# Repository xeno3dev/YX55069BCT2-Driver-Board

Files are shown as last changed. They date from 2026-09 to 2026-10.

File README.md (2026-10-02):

PCB Render



# LumaDD

## Overview

LumaDD is a Custom Display Driver Board designed around a display I got off [Alibaba](https://www.alibaba.com/product-detail/5-5-Vertical-Smart-Home-lcd_1601790231031.html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), with Touch Support. It features HDMI -> MIPI DSI video signal conversion, USB-C for Touch Signals + Power, as well as an onboard ESP32-S3 for display control + touch processing (via USB HID)

## Repo Directory

Folder | Contents
|---|---|
Component Libs | All 3D Models. Footprints, and Symbols used on the PCB
Kicad Project | Schematic + PCB Files
Production Files | BOM + CPL + Netlist + Designator + Gerber Files

## Rough BOM
| Part / Group | What’s included | Qty | Cost (USD) |
| --- | --- | ---: | ---: |
| Converter BGA | [TC358870XBG](https://www.lcsc.com/product-detail/C3008712.html), U1 | 1 | $8.86 |
| ESP32 by itself | [ESP32-S3R8](https://www.lcsc.com/product-detail/C2913194.html), U10 | 1 | $3.02 |
| Flash memory | [GD25Q128EWIGR](https://www.lcsc.com/product-detail/C2982923.html), U11 | 1 | $3.33 |
| HDMI port | [Amphenol 10029449-111RLF](https://www.lcsc.com/product-detail/C427307.html) | 1 | $0.62 |
| USB-C port | [TYPE-C16PIN](https://www.lcsc.com/product-detail/C393939.html) | 1 | $0.06 |
| Display connector | [24-pin FPC](https://www.lcsc.com/product-detail/C132514.html) | 1 | $0.25 |
| Touch connector | [6-pin FPC](https://www.lcsc.com/product-detail/C5343255.html) | 1 | $0.15 |
| Power regulation and input control | Five TLV767 regulators, CH224K, TPS259474 eFuse | 7 | $3.64 |
| Backlight power stage | TPS61165, inductor, diode | 3 | $1.09 |
| Logic level shifters | Two PCA9306, TXS0101, SN74AXC1T45 | 4 | $2.39 |
| ESD / surge protection | D3–D5, U8, U12, U16 | 6 | $1.46 |
| Clock components | 40 MHz crystal and 48 MHz oscillator | 2 | $1.50 |
| Boot / reset buttons | SW3 and SW4 | 2 | $2.29 |
| Capacitors | All BOM capacitors | 72 | $1.97 |
| Resistors | All BOM resistors | 40 | $0.36 |
| MOSFETs | Three BSS138 | 3 | $0.06 |
| Ferrite beads | FB1 and FB2 | 2 | $0.03 |
| **Total parts used** | **148 components** | **148** | **$31.07** |

### Full BOM Located [Here](./Production%20Files/bom.csv)

## License

[Attribution-NonCommercial-ShareAlike 4.0 International](./LICENSE)

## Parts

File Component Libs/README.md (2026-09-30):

# YX55069BCT2 portable KiCad library

`YX55069BCT2.kicad_sym` and `YX55069BCT2.pretty` are self-contained
project libraries. The project tables in `../Kicad Project/` address them by a
project-relative path, so a clone needs neither the Slate113 checkout nor global
KiCad libraries.

The exact requested parts carry their MPN, manufacturer, LCSC part number,
datasheet, and local footprint as symbol properties. `manifest.json` records
the source library and source hash. `tools/build_library.py` reproduces the
library from those sources; normal project use does not run it.

Matching STEP models are stored in `YX55069BCT2.3dshapes` with project-relative
paths. After regenerating the footprint library, run `tools/assign_3d_models.py`
to restore the 3D links in both the library and PCB. The TC358870 BGA STEP came
from EasyEDA/LCSC C3008712, the USB-C STEP from Slate113, and the remaining
models from recorded vendor imports or matching KiCad standard packages.

- `ESP32-S3-WROOM-1-N16R8` uses the PCB-antenna WROOM-1 land pattern. GPIO35,
  GPIO36, and GPIO37 are marked `RESERVED_PSRAM` because N16R8 uses octal
  PSRAM.
- `TC358870XBG(NOK)` is C3008712. Its 1.1 V core/HDMI rails, 1.2 V MIPI D-PHY
  rails, 1.8 V I/O, and 3.3 V I/O/HDMI rails must remain separate.
- `AP2112K-1.2TRG1` was added for the TC358870 1.2 V rail. The requested
  1.8 V and 3.3 V AP2112s and 2.8 V AP2120 remain available.
- The bridge needs an I2C host to set its registers, EDID SRAM and panel
  parameters; it is not a generic plug-and-play MIPI-panel adapter.

See [SOURCING_AND_ARCHITECTURE.md](SOURCING_AND_ARCHITECTURE.md) for sourcing
status and the schematic integration constraints.

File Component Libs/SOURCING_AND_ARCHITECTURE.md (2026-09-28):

# Display bridge sourcing and board architecture

Stock was checked on global LCSC product/catalog pages and DigiKey on
2026-09-24. Search-card availability was not used as evidence.

## Exact board components

This board is HDMI input -> TC358870 -> MIPI DSI panel, with a separate USB-C
USB 2.0 cable for touch. It is not a USB-C DisplayPort Alt Mode display input.
The USB-C connector is therefore only the ESP32 USB device path: D+/D-, ESD,
and two separate 5.1 kohm CC pull-downs. It must not connect to the bridge's
HDMI receiver or DSI output.

| Function | Exact fitted component | LCSC | Documentation |
| --- | --- | --- | --- |
| HDMI input | Amphenol 10029449-001RLF | [C428493](https://www.lcsc.com/product-detail/C428493.html) | [drawing](https://cdn.amphenol-icc.com/media/wysiwyg/files/drawing/10029449.pdf) |
| HDMI to DSI | Toshiba TC358870XBG(NOK) | [C3008712](https://www.lcsc.com/product-detail/C3008712.html) | [datasheet](https://toshiba.semicon-storage.com/info/TC358870XBG_datasheet_en_20171025.pdf?did=28743&prodName=TC358870XBG) |
| Touch HID MCU | ESP32-S3-WROOM-1-N16R8 | [C2913202](https://www.lcsc.com/product-detail/C2913202.html) | [Espressif](https://www.espressif.com/sites/default/files/documentation/esp32-s3-wroom-1_wroom-1u_datasheet_en.pdf) |
| USB-C USB 2.0 | Shou Han TYPE-C16PIN | [C393939](https://www.lcsc.com/product-detail/C393939.html) | — |
| Optional USB-C PD sink | STMicroelectronics STUSB4500QTR | [C2678061](https://www.lcsc.com/product-detail/C2678061.html) | [ST datasheet](https://www.st.com/resource/en/datasheet/stusb4500.pdf) |
| Display FPC | CKMTW F-FPC0M24P-C310 | [C132514](https://www.lcsc.com/product-detail/C132514.html) | — |
| Touch FPC | Xunpu FPC-0.5FX-6PWBH10 | [C5343255](https://www.lcsc.com/product-detail/C5343255.html) | — |
| I2C translation | TI PCA9306DCUR | [C33196](https://www.lcsc.com/product-detail/C33196.html) | [TI](https://www.ti.com/product/PCA9306) |
| USB ESD | ST USBLC6-2SC6 | [C7519](https://www.lcsc.com/product-detail/C7519.html) | [ST](https://www.st.com/resource/en/datasheet/usblc6-2.pdf) |
| 3.3 V LDO | Diodes AP2112K-3.3TRG1 | [C51118](https://www.lcsc.com/product-detail/C51118.html) | [Diodes](https://www.diodes.com/part/view/AP2112) |
| Optional 3.3 V LDO | Seaward Elec SED5120 | [C2838439](https://www.lcsc.com/product-detail/C2838439.html) | [datasheet](https://lcsc.com/datasheet/lcsc_datasheet_2410121612_Seaward-Elec-SED5120_C2838439.pdf) |
| 1.8 V LDO | Diodes AP2112K-1.8TRG1 | [C176944](https://www.lcsc.com/product-detail/C176944.html) | [Diodes](https://www.diodes.com/part/view/AP2112) |
| 2.8 V LDO | Diodes AP2120N-2.8TRG1 | [C6500826](https://www.lcsc.com/product-detail/C6500826.html) | [Diodes](https://www.diodes.com/datasheet/download/AP2120.pdf) |
| 1.2 V LDO | Diodes AP2112K-1.2TRG1 | [C460310](https://www.lcsc.com/product-detail/C460310.html) | [Diodes](https://www.diodes.com/part/view/AP2112) |
| Backlight candidate | TI LP8556SQ-E09/NOPB | [C2679180](https://www.lcsc.com/product-image/C2679180.html) | [TI](https://www.ti.com/lit/ds/symlink/lp8556.pdf) |

The global LCSC product page showed **187** TC358870XBG(NOK) available to ship.
It is HDMI 1.4b RX to MIPI DSI 1.1 TX: 297 MHz HDMI maximum, one four-lane DSI
link at up to 1 Gbit/s/lane, or two four-lane links. The documented single-link
limits are 2558 pixels wide at 24 bpp and 3411 at 16 bpp. It has no scaler or
deinterlacer. With no panel model, resolution, lane count, DCS sequence,
refresh range, backlight string, or FPC pinout, compatibility remains unknown.

TC358870 is **register-configured, not proprietary-firmware booted**. A host
sets its I2C registers, EDID SRAM, and panel control; there is no required
vendor SPI image. Public third-party source exists at
[CNflysky/TC358870](https://github.com/CNflysky/TC358870), but it is not a
manufacturer-supported universal panel binary.

## USB-C DisplayPort Alt Mode -> MIPI DSI

No current global-LCSC or DigiKey part was verified that meets all of: USB-C DP
Alt Mode input, MIPI DSI output, open/publicly sufficient implementation, and
no proprietary vendor firmware.

| Candidate | Direction/capability | Firmware class | Constraint that fails |
| --- | --- | --- | --- |
| LT7911D / C5310990 | Type-C/DP1.2 to MIPI DSI/CSI/LVDS, 1.5 Gbit/s/lane | Factory embedded MCU; confidential documentation | Global LCSC direct route reports part not found. |
| LT7911UXC / C5310989 | Type-C/DP1.4 to MIPI/CSI/LVDS | Factory embedded MCU and SPI-flash firmware | Global LCSC says **Not available now**. |
| Analogix ANX7530/ANX7580 | DP to dual/single MIPI DSI | Public non-proprietary implementation not established | Manufacturer capability exists, but no global LCSC/DigiKey stock was verified. [Analogix](https://www.analogix.com/en/mipi/converters/bridges) |
| TC358870XBG | **HDMI** to DSI | Register-configured | In stock, but wrong input direction for this search. |

Any discrete DP-to-DSI implementation still needs Type-C CC/PD policy,
orientation/lane mapping and normally a high-speed mux. Four DP lanes consume
the SuperSpeed pairs; USB 3.x coexistence means two-lane DP and less bandwidth.
This board needs none of that because its video and touch cables are separate.

## USB-C DP Alt Mode -> HDMI versus MCDP5200B0T

`MCDP5200B0T` was live at DigiKey with **445 pieces**: MPN `MCDP5200B0T`,
orderable as `2763-MCDP5200B0TCT-ND` cut tape,
`2763-MCDP5200B0TTR-ND` reel, or `2763-MCDP5200B0TDKR-ND` Digi-Reel.
[DigiKey listing](https://www.digikey.com/en/products/detail/kinetic-technologies/MCDP5200B0T/13557894).
It has DP1.4a Alt Mode, HDMI 2.0b, HBR3, up to 4K60 RGB/YCC444 or 4K120 YCC420,
and USB3.1 demux. It fails the request because secure boot authenticates a
signed application image from external 16-Mbit SPI flash:
[datasheet brief](https://mm.digikey.com/Volume0/opasdata/d220001/medias/docus/6727/MCDP5200B0T%20Datasheet.pdf).

No currently in-stock functional alternative without proprietary vendor
firmware was verified.

| Candidate | What it replaces | Firmware class | Constraint that fails |
| --- | --- | --- | --- |
| Parade PS176 / C209703 | DP/DP Alt Mode to HDMI 2.0, 4K60 | Factory internal SPI ROM/microcode | Global LCSC says **Not available now**; no open firmware. [Parade](https://www.paradetech.com/products/ps176/) |
| Lontium LT8711GX / C5310994 | Type-C/DP1.4a to HDMI2.1 with CC/PD | Embedded MCU and SPI flash for firmware/HDCP keys | Global LCSC says **Not available now** and the firmware is closed. [LCSC](https://www.lcsc.com/product-detail/C5310994.html) |
| Kinetic STDP2690ADT | Native DP to DP++/HDMI-class output | Internal ROM plus optional external custom flash | DigiKey reports **0 stock** and discontinued. It is HDMI 1.2a/DP++ class and lacks MCDP5200's integrated Type-C/USB3.1 demux. [DigiKey](https://www.digikey.com/en/products/detail/kinetic-technologies/STDP2690ADT/15976326) |

## Schematic integration checklist

- Use controlled-impedance, length-matched HDMI TMDS and MIPI DSI pairs. Route
  DDC, HPD and CEC exactly per the bridge reference material.
- TC358870 needs 1.1 V core/HDMI rails, separate 1.2 V MIPI rails, 1.8 V I/O,
  3.3 V HDMI/I/O rails, local decoupling, 2 kohm REXT, 40-50 MHz 1.8 V REFCLK,
  RESETN, I2C, and accessible test/programming pads.
- SED5120 is an optional nominal 3.3 V regulator, not a drop-in guarantee for
  AP2112K-3.3: calculate worst-case SOT-223 dissipation from the selected input
  voltage and load, and use the output capacitance specified by its datasheet.
- Map the display FPC only after obtaining its panel drawing. Connector pin
  count does not prove MIPI pinout or video-mode compatibility.
- PCA9306 translates open-drain I2C only. Use the lower rail on VREF1,
  VREF2/EN through 200 kohm to the high rail, and pull-ups on both sides.
  Translate any push-pull touch reset/interrupt signal separately.
- If STUSB4500QTR is fitted on the USB-C touch/power port, its CC pins own
  attachment and PD-sink negotiation. Do not also fit the two discrete 5.1
  kohm CC pull-downs. It does not add DisplayPort Alt Mode capability.
- GT911 requirements still need the actual panel drawing. Confirm VDDIO,
  INT/RST boot levels, address selection, and whether 2.8 V is correct.
- CircuitPython supports custom `usb_hid.Device` descriptors, so ESP32-S3 can
  expose a HID digitizer. Stock mouse HID is not a multi-touch digitizer.
  [CircuitPython API](https://docs.circuitpython.org/en/stable/shared-bindings/usb_hid/)
- LP8556 is a six-channel boost driver. Inductor, diode, output capacitors,
  current setting and string count are intentionally marked TBD until the
  panel backlight data is known.

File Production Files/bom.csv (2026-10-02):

Designator | Footprint | Quantity | Value | LCSC Part #
C1, C17, C19, C20, C22, C23, C25, C26, C28, C3 | 0603 | 10 | 4.7 µF | C69335
C10 | 0603 | 1 | 1.0µF | C5673
C11 | C0402 | 1 | 1 nF | C14442
C12 | C0402 | 1 | 2.2 nF | C84703
C13 | C1206 | 1 | 10 uF | C100122
C14, C15, C16, C29, C30, C36, C39, C4, C40, C41, C42, C43, C44, C45, C46, C47, C5, C59, C6, C62, C63, C64, C7, C8, C9 | C0603 | 25 | 100nF | C1591
C147 | 0603 | 1 | 100nF | C1591
C156, C157 | 0603 | 2 | 100pF | C14858
C18, C2, C21, C24, C27, C65 | 0603 | 6 | 100 nF | C1591
C31, C33, C34, C35, C48, C58, C69 | C0603 | 7 | 10uF | C77044
C32, C68 | CL05A105KA5NQNC | 2 | 1uF | C52923
C37, C38 | C0402 | 2 | 15 pF | C86285
C49, C50, C51, C52, C61 | C0603 | 5 | 1uF | C29936
C53, C54, C55, C56, C57, C60 | C0603 | 6 | 2.2uF | C23630
C66 | C0402 | 1 | 220 nF | C16772
C67 | C0805 | 1 | 4.7µF | C2897302
D2 | SOD-123FL_L2.7-W1.8-LS3.8-RD | 1 | S16 | C405304
D3 | USON-10_L2.5-W1.0-P0.50-BL | 1 | TPD4E05U06DQAR | C138714
D4, D5 | USON-10_L2.5-W1.0-P0.50-BL | 2 | TPD4E02B04DQAR | C106794
FB1, FB2 | 0603 | 2 | FerriteBead | C14709
FPC1 | FPC-SMD_P0.50-24P_XJ-FGS | 1 | FPC0.5-24P | C132514
FPC2 | FPC-SMD_FPC-0.5FX-6PWBH10 | 1 | FPC-0.5FX-6PWBH10 | C5343255
J1 | HDMI_A_Amphenol_10029449-x01xLF_Horizontal | 1 | 10029449-111RLF | C427307
L3 | IND-SMD_L7.1-W6.6 | 1 | 10µH | C112288
OSC1 | OSC-SMD_4P-L2.0-W1.6-BL | 1 | OT7EL89CJI-111YLC-48M | C7434946
Q1, Q2, Q4 | SOT-23-3_L2.9-W1.6-P1.90-LS2.8-BR | 3 | BSS138_C112239 | C112239
R1 | R0402 | 1 | 2.00 kOhm | C60488
R10 | R0402 | 1 | 31.6 kOhm | C11463
R100, R96 | 0603 | 2 | 10kΩ | C840630
R101, R104, R106, R108, R97, R98 | 0603 | 6 | 4.7kΩ | C163914
R103, R99 | 0603 | 2 | 200kΩ | C118142
R105, R107, R110 | 0603 | 3 | 100kΩ | C25803
R11, R14, R2, R6, R7 | R0402 | 5 | 10 kOhm | C60490
R12 | R0402 | 1 | 0 Ohm | C106231
R13 | R0402 | 1 | 22 Ohm | C114765
R15, R16 | R0402 | 2 | 27 Ohm | C138021
R17 | R0402 | 1 | 43.2 kOhm | C25894
R18, R19 | 0603 | 2 | 47k | C2907042
R20 | 0603 | 1 | 100k | C14675
R21, R24 | 0603 | 2 | 1k | C22548
R22, R23, R27 | R0402 | 3 | 100 Ohm | C106232
R26 | R0402 | 1 | 1.10 kOhm | C25860
R28 | R0402 | 1 | 100 kOhm | C25741
R3 | 0805 | 1 | 49.9 kΩ | C17719
R4, R5 | 0805 | 2 | 100 kΩ | C149504
R8 | R0402 | 1 | 348 kOhm | C25780
R9 | R0402 | 1 | 5 Ohm | C6888654
SW3 | KEY-SMD_KMR2XXGXXX | 1 | BOOT | C99271
SW4 | KEY-SMD_KMR2XXGXXX | 1 | RESET | C99271
U1 | P-VFBGA-80_L7.0-W7.0-R10-C10-P0.65-TL | 1 | TC358870XBG(NOK) | C3008712
U10 | QFN-56_L7.0-W7.0-P0.40-TL-EP4.0 | 1 | ESP32-S3R8 | C2913194
U11 | WSON-8_L6.0-W5.0-P1.27-TL-EP | 1 | GD25Q128EWIGR | C2982923
U12 | SOT-23-6 | 1 | USBLC6-2SC6 | C7519
U13 | SC-70-6_L2.0-W1.3-P0.65-LS2.1-BL-1 | 1 | SN74AXC1T45DCKR | C2677392
U14 | SOT-23-6_L2.9-W1.6-P0.95-LS2.8-BR | 1 | TXS0101DBVR | C132604
U15 | SOT-23-6_L2.9-W1.6-P0.95-LS2.8-BR | 1 | TPS61165DBVR | C58756
U16 | WSON-6_L2.0-W2.0-P0.65-BL-EP | 1 | TVS0500DRVR | C609571
U2, U7 | WSON-6_L2.0-W2.0-P0.65-TL-EP | 2 | TLV76701DRVR | C2863998
U3 | SSOP-10-1EP_3.9x4.9mm_P1mm_EP2.1x3.3mm | 1 | CH224K | C970725
U4 | WSON-6_L2.0-W2.0-P0.65-BL-EP | 1 | TLV76718DRVR | C2870458
U5 | WSON-6_L2.0-W2.0-P0.65-BL-EP | 1 | TLV76728DRVR | C2865665
U6 | WSON-6_L2.0-W2.0-P0.65-TL-EP | 1 | TLV76733DRVR | C2848334
U62, U64 | SSOP-8_L2.0-W2.3-P0.50-LS3.1-BR | 2 | PCA9306DCUR | C33196
U8 | DFN-10_L2.5-W1.0-P0.50-BL | 1 | ESD7104MUTAG_C2987068 | C2987068
U9 | VQFN-10_L2.0-W2.0-P0.45-TL | 1 | TPS259474LRPWR | C2864845
USB1 | USB-C-SMD_TYPE-C16PIN | 1 | TYPE-C16PIN | C393939
X1 | CRYSTAL-SMD_4P-L3.2-W2.5-BL | 1 | ABM8-40.000MHZ-10-D1G-T | C1986736

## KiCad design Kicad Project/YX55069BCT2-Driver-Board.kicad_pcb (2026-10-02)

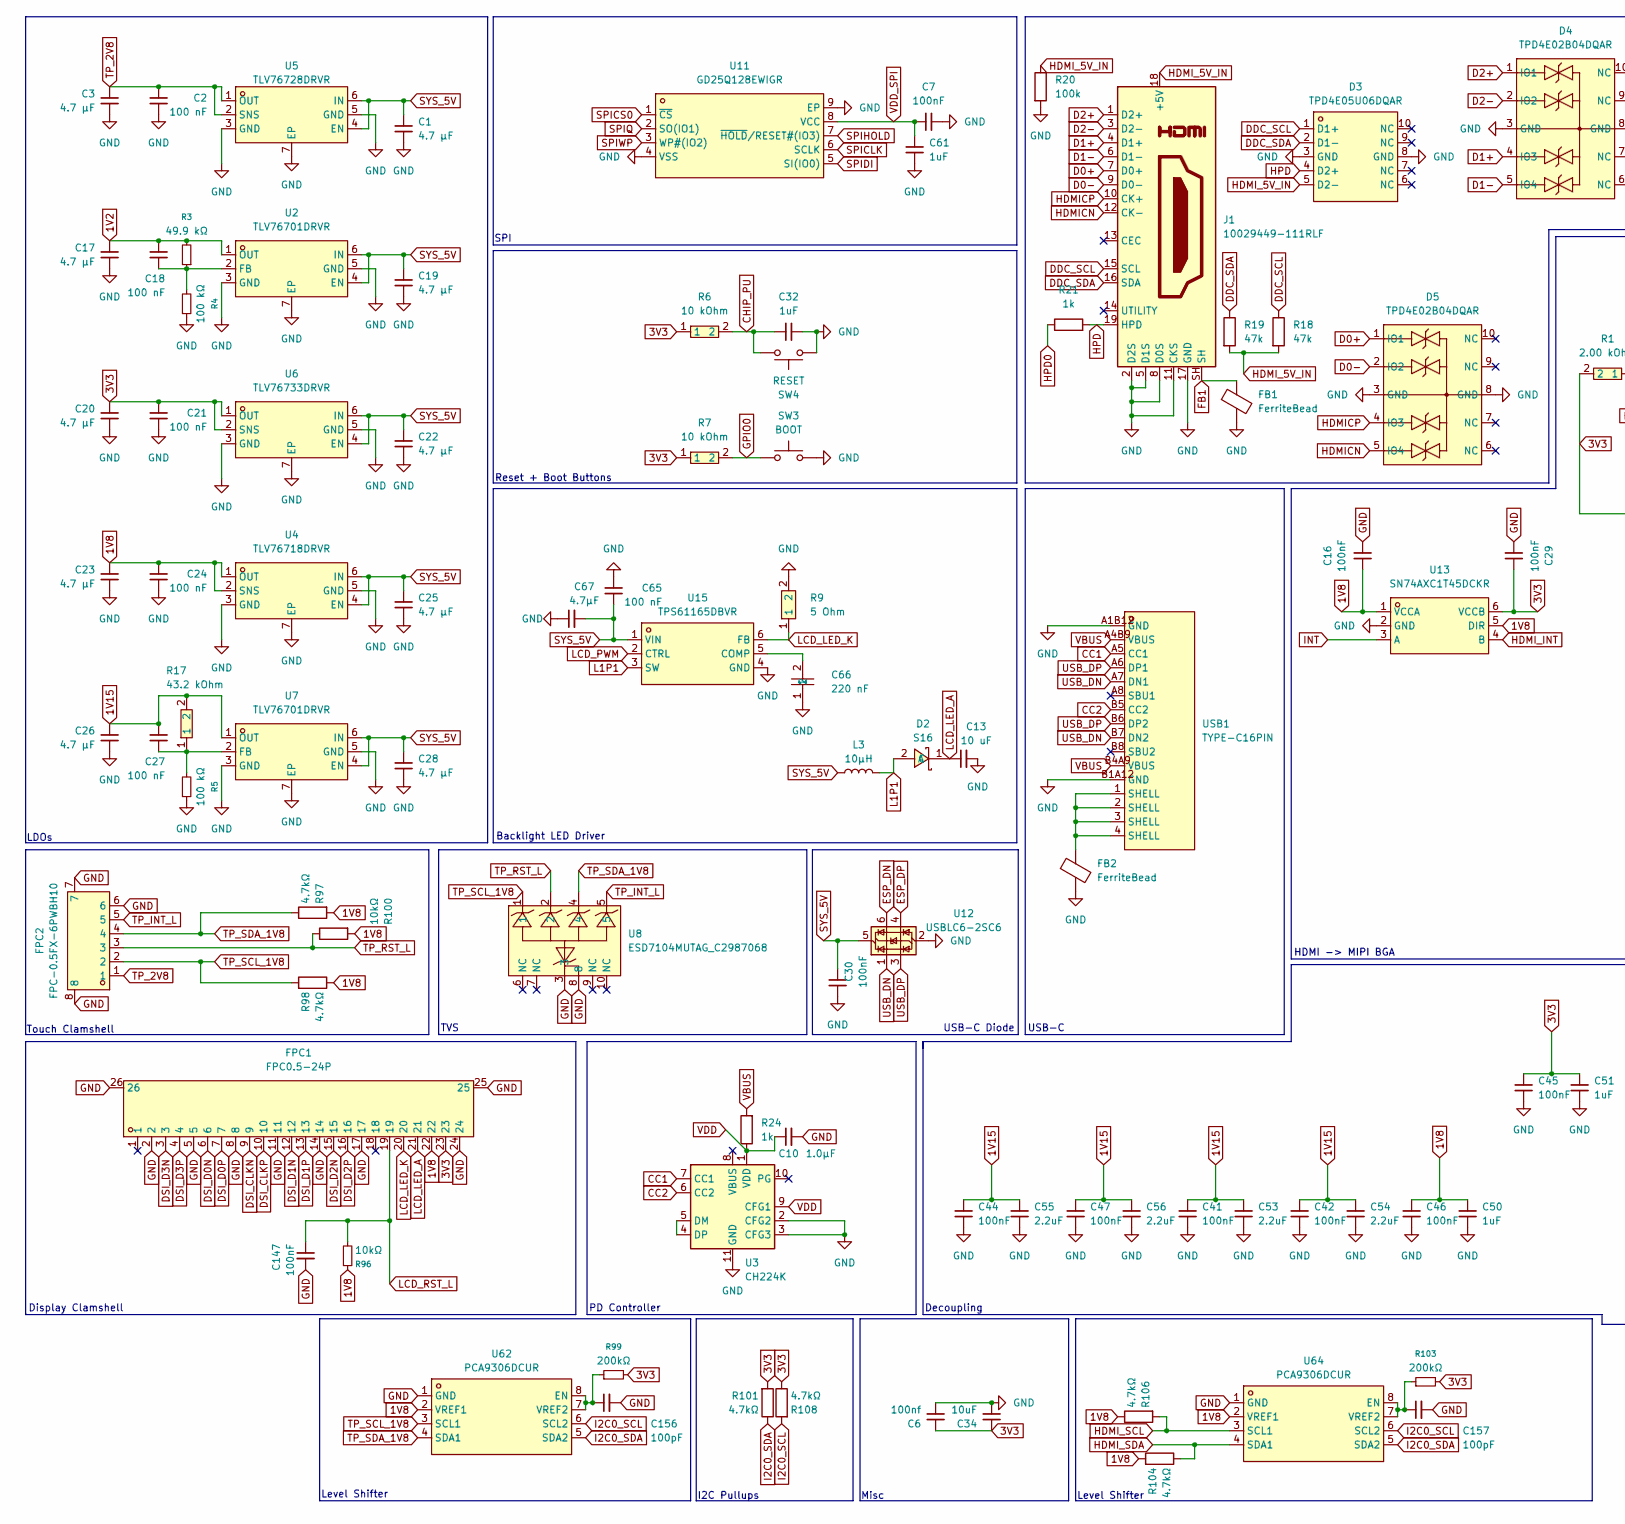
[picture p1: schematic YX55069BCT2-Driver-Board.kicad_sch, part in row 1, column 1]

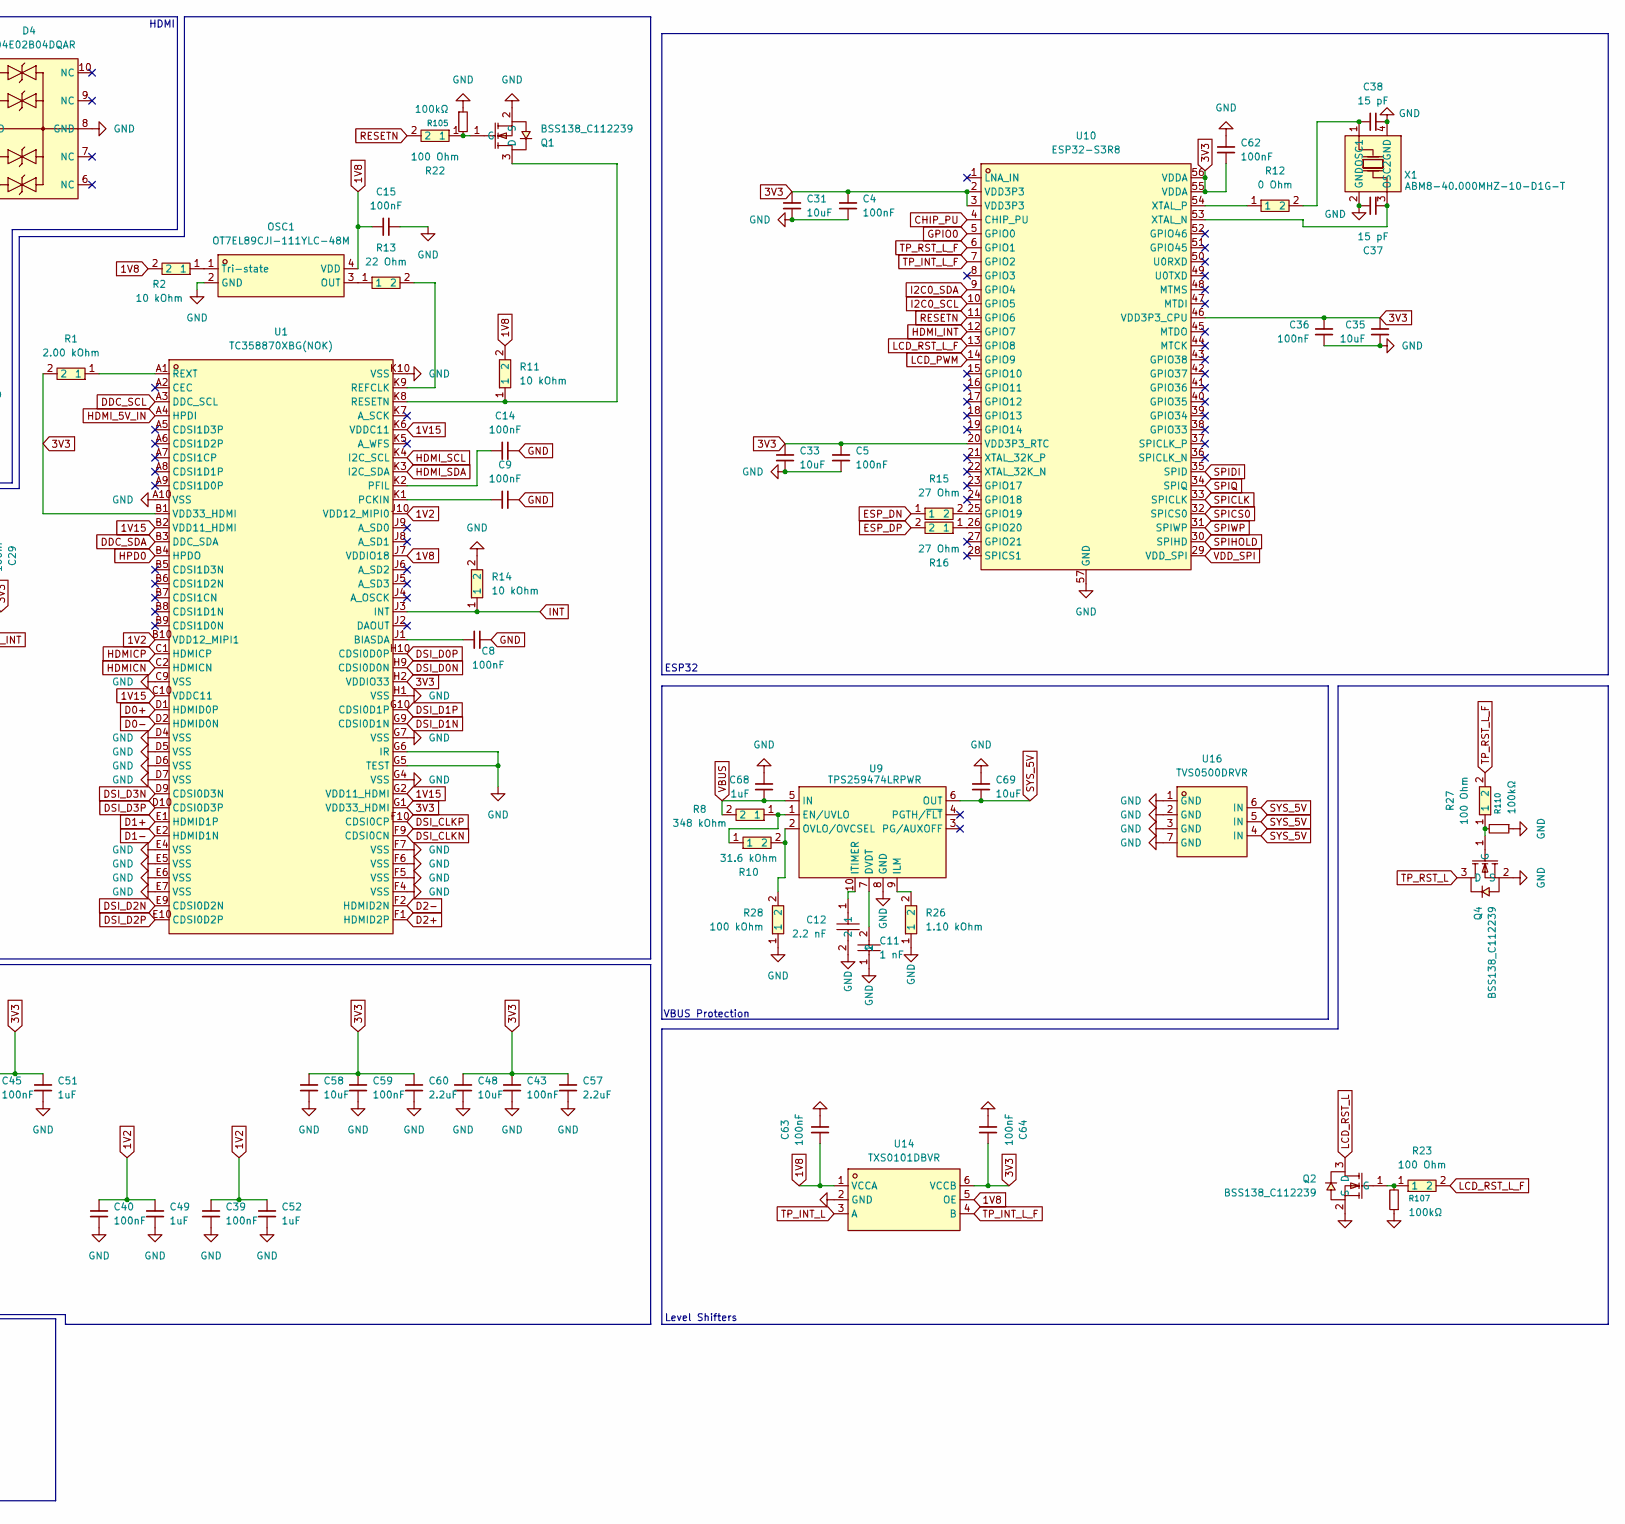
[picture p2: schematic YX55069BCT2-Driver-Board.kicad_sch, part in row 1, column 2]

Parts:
C1, C3, C17, C19, C20, C22, C23, C25, C26, C28: 4.7 µF; C_0603_1608Metric; LCSC C69335
C2, C18, C21, C24, C27, C65: 100 nF; C_0603_1608Metric; LCSC C1591
C4, C5, C7, C8, C9, C14, C15, C16, C29, C30, C36, C39, C40, C41, C42, C43, C44, C45, C46, C47, C59, C62, C63, C64: 100nF; C0603; LCSC C1591
C6: 100nf; C0603; LCSC C1591
C10: 1.0µF; C_0603_1608Metric; MPN CL10A105KA8NNNC; LCSC Part C5673
C11: 1 nF; C0402; Tolerance 10%; Voltage 50 V; MPN CL05B102KB5NNNC; LCSC C14442
C12: 2.2 nF; C0402; Tolerance 10%; Voltage 50 V; MPN CL05B222KB5NNNC; LCSC C84703
C13: 10 uF; C1206; LCSC Part C100122
C31, C33, C34, C35, C48, C58, C69: 10uF; C0603; LCSC C77044
C32, C68: 1uF; CL05A105KA5NQNC; LCSC C52923
C37, C38: 15 pF; C0402; LCSC C86285
C49, C50, C51, C52, C61: 1uF; C0603; LCSC C29936
C53, C54, C55, C56, C57, C60: 2.2uF; C0603; LCSC C23630
C66: 220 nF; C0402; Tolerance 10%; Voltage 16 V; MPN CL05B224KO5NNNC; LCSC C16772
C67: 4.7µF; C0805; LCSC Part C2897302
C147: 100nF; C_0603_1608Metric; MPN CL10B104KB8NNNC; LCSC Part C1591
C156, C157: 100pF; C_0603_1608Metric; MPN CL10C101JB8NNNC; LCSC Part C14858
D2: S16; SOD-123FL_L2.7-W1.8-LS3.8-RD; MPN S16; LCSC C405304
D3: TPD4E05U06DQAR; USON-10_L2.5-W1.0-P0.50-BL; MPN TPD4E05U06DQAR; LCSC C138714
D4, D5: TPD4E02B04DQAR; USON-10_L2.5-W1.0-P0.50-BL; MPN TPD4E02B04DQAR; LCSC C106794
FB1, FB2: FerriteBead; L_0603_1608Metric; LCSC C14709
FPC1: FPC0.5-24P; FPC-SMD_P0.50-24P_XJ-FGS; MPN F-FPC0M24P-C310; LCSC Part C132514
FPC2: FPC-0.5FX-6PWBH10; FPC-SMD_FPC-0.5FX-6PWBH10; MPN FPC-0.5FX-6PWBH10; LCSC Part C5343255
J1: 10029449-111RLF; HDMI_A_Amphenol_10029449-x01xLF_Horizontal; MPN 10029449-001RLF; LCSC C427307
L3: 10µH; IND-SMD_L7.1-W6.6; MPN SPM6530T-100M; LCSC Part C112288
OSC1: OT7EL89CJI-111YLC-48M; OSC-SMD_4P-L2.0-W1.6-BL; Supply Voltage 1.8–3.3 V; MPN OT7EL89CJI-111YLC-48M; LCSC C7434946
Q1, Q2, Q4: BSS138_C112239; SOT-23-3_L2.9-W1.6-P1.90-LS2.8-BR; MPN BSS138; LCSC C112239
R1: 2.00 kOhm; R0402; Tolerance 1%; MPN RC0402FR-072KL; LCSC C60488
R2, R6, R7, R11, R14: 10 kOhm; R0402; Tolerance 1%; MPN RC0402FR-0710KL; LCSC C60490
R3: 49.9 kΩ; R_0805_2012Metric; LCSC C17719
R4, R5: 100 kΩ; R_0805_2012Metric; LCSC C149504
R8: 348 kOhm; R0402; Voltage 50 V; Tolerance 1%; MPN 0402WGF3483TCE; LCSC C25780
R9: 5 Ohm; R0402; Voltage 50 V; Tolerance 1%; MPN CSRT0402FT5R00; LCSC C6888654
R10: 31.6 kOhm; R0402; Voltage 50 V; Tolerance 1%; MPN 0402WGF3162TCE; LCSC C11463
R12: 0 Ohm; R0402; Tolerance 1%; MPN RC0402FR-070RL; LCSC C106231
R13: 22 Ohm; R0402; Tolerance 1%; MPN RC0402FR-0722RL; LCSC C114765
R15, R16: 27 Ohm; R0402; Tolerance 1%; MPN RC0402FR-0727RL; LCSC C138021
R17: 43.2 kOhm; R0402; Voltage 50 V; Tolerance 1%; MPN 0402WGF4322TCE; LCSC C25894
R18, R19: 47k; R_0603_1608Metric; LCSC C2907042
R20: 100k; R_0603_1608Metric; LCSC C14675
R21, R24: 1k; R_0603_1608Metric; LCSC C22548
R22, R23, R27: 100 Ohm; R0402; Tolerance 1%; MPN RC0402FR-07100RL; LCSC C106232
R26: 1.10 kOhm; R0402; Voltage 50 V; Tolerance 1%; MPN 0402WGF1101TCE; LCSC C25860
R28: 100 kOhm; R0402; Voltage 50 V; Tolerance 1%; MPN 0402WGF1003TCE; LCSC C25741
R96, R100: 10kΩ; R_0603_1608Metric; MPN CR0603-FX-1002ELF; LCSC Part C840630
R97, R98, R101, R104, R106, R108: 4.7kΩ; R_0603_1608Metric; MPN WR06X4701FTL; LCSC Part C163914
R99, R103: 200kΩ; R_0603_1608Metric; MPN ERJ3EKF2003V; LCSC Part C118142
R105, R107, R110: 100kΩ; R_0603_1608Metric; MPN 0603WAF1003T5E; LCSC Part C25803
SW3: BOOT; KEY-SMD_KMR2XXGXXX; MPN KMR231GLFS; LCSC Part C99271
SW4: RESET; KEY-SMD_KMR2XXGXXX; MPN KMR231GLFS; LCSC Part C99271
U1: TC358870XBG(NOK); P-VFBGA-80_L7.0-W7.0-R10-C10-P0.65-TL; MPN TC358870XBG(NOK); LCSC C3008712
U2, U7: TLV76701DRVR; WSON-6_L2.0-W2.0-P0.65-TL-EP; Output Voltage 1.0 V; MPN TLV76701DRVR; LCSC C2863998
U3: CH224K; SSOP-10-1EP_3.9x4.9mm_P1mm_EP2.1x3.3mm; MPN CH224K; LCSC Part C970725
U4: TLV76718DRVR; WSON-6_L2.0-W2.0-P0.65-BL-EP; Output Voltage 1.8 V; MPN TLV76718DRVR; LCSC C2870458
U5: TLV76728DRVR; WSON-6_L2.0-W2.0-P0.65-BL-EP; Output Voltage 2.8 V; MPN TLV76728DRVR; LCSC C2865665
U6: TLV76733DRVR; WSON-6_L2.0-W2.0-P0.65-TL-EP; Output Voltage 3.3 V; MPN TLV76733DRVR; LCSC C2848334
U8: ESD7104MUTAG_C2987068; DFN-10_L2.5-W1.0-P0.50-BL; MPN ESD7104MUTAG; LCSC Part C2987068
U9: TPS259474LRPWR; VQFN-10_L2.0-W2.0-P0.45-TL; MPN TPS259474LRPWR; LCSC C2864845
U10: ESP32-S3R8; QFN-56_L7.0-W7.0-P0.40-TL-EP4.0; MPN ESP32-S3R8; LCSC C2913194
U11: GD25Q128EWIGR; WSON-8_L6.0-W5.0-P1.27-TL-EP; MPN GD25Q128EWIGR; LCSC C2982923
U12: USBLC6-2SC6; SOT-23-6; LCSC C7519
U13: SN74AXC1T45DCKR; SC-70-6_L2.0-W1.3-P0.65-LS2.1-BL-1; MPN SN74AXC1T45DCKR; LCSC Part C2677392
U14: TXS0101DBVR; SOT-23-6_L2.9-W1.6-P0.95-LS2.8-BR; MPN TXS0101DBVR; LCSC C132604
U15: TPS61165DBVR; SOT-23-6_L2.9-W1.6-P0.95-LS2.8-BR; MPN TPS61165DBVR; LCSC C58756
U16: TVS0500DRVR; WSON-6_L2.0-W2.0-P0.65-BL-EP; MPN TVS0500DRVR; LCSC C609571
U62, U64: PCA9306DCUR; SSOP-8_L2.0-W2.3-P0.50-LS3.1-BR; MPN PCA9306DCUR; LCSC Part C33196
USB1: TYPE-C16PIN; USB-C-SMD_TYPE-C16PIN; MPN TYPE-C16PIN; LCSC C393939
X1: ABM8-40.000MHZ-10-D1G-T; CRYSTAL-SMD_4P-L3.2-W2.5-BL; MPN ABM8-40.000MHZ-10-D1G-T; LCSC C1986736

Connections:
1V2: C17.2, C18.2, C39.2, C40.2, C49.2, C52.2, R3.2, U1.B10 (VDD12_MIPI1), U1.J10 (VDD12_MIPI0), U2.1 (OUT)
1V8: C15.2, C16.2, C23.2, C24.2, C46.2, C50.2, C63.2, FPC1.22, OSC1.4 (VDD), R2.2, R11.2, R96.1, R97.2, R98.1, R100.2, R104.2, R106.1, U1.J7 (VDDIO18), U4.1 (OUT), U4.2 (SNS), U13.1 (VCCA), U13.5 (DIR), U14.1 (VCCA), U14.5 (OE), U62.2 (VREF1), U64.2 (VREF1)
1V15: C26.2, C27.2, C41.2, C42.2, C44.2, C47.2, C53.2, C54.2, C55.2, C56.2, R17.2, U1.B2 (VDD11_HDMI), U1.C10 (VDDC11), U1.G2 (VDD11_HDMI), U1.K6 (VDDC11), U7.1 (OUT)
3V3: C4.2, C5.2, C6.2, C20.2, C21.2, C29.2, C31.2, C33.2, C34.2, C35.2, C36.2, C43.2, C45.2, C48.2, C51.2, C57.2, C58.2, C59.2, C60.2, C62.2, C64.2, FPC1.23, R1.2, R6.1, R7.1, R99.2, R101.2, R103.2, R108.1, U1.B1 (VDD33_HDMI), U1.G1 (VDD33_HDMI), U1.H2 (VDDIO33), U6.1 (OUT), U6.2 (SNS), U10.2 (VDD3P3), U10.3 (VDD3P3), U10.20 (VDD3P3_RTC), U10.46 (VDD3P3_CPU), U10.55 (VDDA), U10.56 (VDDA), U13.6 (VCCB), U14.6 (VCCB)
CC1: U3.7 (CC1), USB1.A5 (CC1)
CC2: U3.6 (CC2), USB1.B5 (CC2)
CHIP_PU: C32.2, R6.2, SW4.1, U10.4 (CHIP_PU)
D0+: D5.1 (IO1), J1.7 (D0+), U1.D1 (HDMID0P)
D0-: D5.2 (IO2), J1.9 (D0-), U1.D2 (HDMID0N)
D1+: D4.4 (IO3), J1.4 (D1+), U1.E1 (HDMID1P)
D1-: D4.5 (IO4), J1.6 (D1-), U1.E2 (HDMID1N)
D2+: D4.1 (IO1), J1.1 (D2+), U1.F1 (HDMID2P)
D2-: D4.2 (IO2), J1.3 (D2-), U1.F2 (HDMID2N)
DDC_SCL: D3.1 (D1+), J1.15 (SCL), R18.1, U1.A3 (DDC_SCL)
DDC_SDA: D3.2 (D1-), J1.16 (SDA), R19.1, U1.B3 (DDC_SDA)
DSI_CLKN: FPC1.9, U1.F9 (CDSI0CN)
DSI_CLKP: FPC1.10, U1.F10 (CDSI0CP)
DSI_D0N: FPC1.6, U1.H9 (CDSI0D0N)
DSI_D0P: FPC1.7, U1.H10 (CDSI0D0P)
DSI_D1N: FPC1.12, U1.G9 (CDSI0D1N)
DSI_D1P: FPC1.13, U1.G10 (CDSI0D1P)
DSI_D2N: FPC1.15, U1.E9 (CDSI0D2N)
DSI_D2P: FPC1.16, U1.E10 (CDSI0D2P)
DSI_D3N: FPC1.3, U1.D9 (CDSI0D3N)
DSI_D3P: FPC1.4, U1.D10 (CDSI0D3P)
ESP_DN: R15.1, U12.6 (I/O1)
ESP_DP: R16.2, U12.4 (I/O2)
FB1: FB1.1, J1.SH
GND: C1.2, C2.1, C3.1, C4.1, C5.1, C6.1, C7.1, C8.1, C9.1, C10.2, C11.1, C12.2, C13.2, C14.1, C15.1, C16.1, C17.1, C19.2, C20.1, C21.1, C22.2, C23.1, C24.1, C25.2, C26.1, C28.2, C29.1, C30.2, C31.1, C32.1, C33.1, C34.1, C35.1, C36.1, C37.1, C38.1, C39.1, C40.1, C41.1, C42.1, C43.1, C44.1, C45.1, C46.1, C47.1, C48.1, C49.1, C50.1, C51.1, C52.1, C53.1, C54.1, C55.1, C56.1, C57.1, C58.1, C59.1, C60.1, C61.1, C62.1, C63.1, C64.1, C65.2, C66.1, C67.1, C68.1, C69.2, C147.2, C156.2, C157.2, D3.3 (GND), D3.8 (GND), D4.3 (GND), D4.8 (GND), D5.3 (GND), D5.8 (GND), FB1.2, FB2.2, FPC1.2, FPC1.5, FPC1.8, FPC1.11, FPC1.14, FPC1.17, FPC1.24, FPC1.25, FPC1.26, FPC2.6, FPC2.7, FPC2.8, J1.2 (D2S), J1.5 (D1S), J1.8 (D0S), J1.11 (CKS), J1.17 (GND), OSC1.2 (GND), Q1.2 (S), Q2.2 (S), Q4.2 (S), R4.1, R5.1, R9.2, R14.2, R20.2, R26.1, R28.1, R105.1, R107.1, R110.1, SW3.2, SW4.2, U1.A10 (VSS), U1.C9 (VSS), U1.D4 (VSS), U1.D5 (VSS), U1.D6 (VSS), U1.D7 (VSS), U1.E4 (VSS), U1.E5 (VSS), U1.E6 (VSS), U1.E7 (VSS), U1.F4 (VSS), U1.F5 (VSS), U1.F6 (VSS), U1.F7 (VSS), U1.G4 (VSS), U1.G5 (TEST), U1.G6 (IR), U1.G7 (VSS), U1.H1 (VSS), U1.K10 (VSS), U2.3 (GND), U2.5 (GND), U2.7 (EP), U3.2 (CFG2), U3.3 (CFG3), U3.11 (GND), U4.3 (GND), U4.5 (GND), U4.7 (EP), U5.3 (GND), U5.5 (GND), U5.7 (EP), U6.3 (GND), U6.5 (GND), U6.7 (EP), U7.3 (GND), U7.5 (GND), U7.7 (EP), U8.3, U8.8, U9.8 (GND), U10.57 (GND), U11.4 (VSS), U11.9 (EP), U12.2 (GND), U13.2 (GND), U14.2 (GND), U15.4 (GND), U16.1 (GND), U16.2 (GND), U16.3 (GND), U16.7 (GND), U62.1 (GND), U64.1 (GND), USB1.A1B12 (GND), USB1.B1A12 (GND), X1.2 (GND), X1.4 (GND)
GPIO0: R7.2, SW3.1, U10.5 (GPIO0)
HDMICN: D5.5 (IO4), J1.12 (CK-), U1.C2 (HDMICN)
HDMICP: D5.4 (IO3), J1.10 (CK+), U1.C1 (HDMICP)
HDMI_5V_IN: D3.5 (D2-), J1.18 (+5V), R18.2, R19.2, R20.1, U1.A4 (HPDI)
HDMI_INT: U10.12 (GPIO7), U13.4 (B)
HDMI_SCL: R106.2, U1.K4 (I2C_SCL), U64.3 (SCL1)
HDMI_SDA: R104.1, U1.K3 (I2C_SDA), U64.4 (SDA1)
HPD: D3.4 (D2+), J1.19 (HPD), R21.2
HPD0: R21.1, U1.B4 (HPDO)
I2C0_SCL: R108.2, U10.10 (GPIO5), U62.6 (SCL2), U64.6 (SCL2)
I2C0_SDA: R101.1, U10.9 (GPIO4), U62.5 (SDA2), U64.5 (SDA2)
INT: R14.1, U1.J3 (INT), U13.3 (A)
L1P1: D2.2 (A), L3.2, U15.3 (SW)
LCD_LED_A: C13.1, D2.1 (C), FPC1.21
LCD_LED_K: FPC1.20, R9.1, U15.6 (FB)
LCD_PWM: U10.14 (GPIO9), U15.2 (CTRL)
LCD_RST_L: C147.1, FPC1.19, Q2.3 (D), R96.2
LCD_RST_L_F: R23.2, U10.13 (GPIO8)
unnamed: FB2.1, USB1.1 (SHELL), USB1.2 (SHELL), USB1.3 (SHELL), USB1.4 (SHELL)
unnamed: OSC1.3 (OUT), R13.1
unnamed: OSC1.1 (Tri-state), R2.1
unnamed: Q1.3 (D), R11.1, U1.K8 (RESETN)
unnamed: Q1.1 (G), R22.1, R105.2
unnamed: Q2.1 (G), R23.1, R107.2
unnamed: Q4.1 (G), R27.1, R110.2
unnamed: C8.2, U1.J1 (BIASDA)
unnamed: C9.2, U1.K1 (PCKIN)
unnamed: C14.2, U1.K2 (PFIL)
unnamed: R13.2, U1.K9 (REFCLK)
unnamed: R1.1, U1.A1 (REXT)
unnamed: C18.1, R3.1, R4.2, U2.2 (FB)
unnamed: U3.4 (DP), U3.5 (DM)
unnamed: C27.1, R5.2, R17.1, U7.2 (FB)
unnamed: C11.2, U9.7 (DVDT)
unnamed: R8.1, R10.1, U9.1 (EN/UVLO)
unnamed: R26.2, U9.9 (ILM)
unnamed: C12.1, U9.10 (ITIMER)
unnamed: R10.2, R28.2, U9.2 (OVLO/OVCSEL)
unnamed: R15.2, U10.25 (GPIO19)
unnamed: R16.1, U10.26 (GPIO20)
unnamed: C37.2, U10.53 (XTAL_N), X1.3 (OSC2)
unnamed: R12.1, U10.54 (XTAL_P)
unnamed: C66.2, U15.5 (COMP)
unnamed: C156.1, R99.1, U62.7 (VREF2), U62.8 (EN)
unnamed: C157.1, R103.1, U64.7 (VREF2), U64.8 (EN)
unnamed: C38.2, R12.2, X1.1 (OSC1)
RESETN: R22.2, U10.11 (GPIO6)
SPICLK: U10.33 (SPICLK), U11.6 (SCLK)
SPICS0: U10.32 (SPICS0), U11.1 (~CS)
SPIDI: U10.35 (SPID), U11.5 (SI(IO0))
SPIHOLD: U10.30 (SPIHD), U11.7 (~HOLD/RESET#(IO3))
SPIQ: U10.34 (SPIQ), U11.2 (SO(IO1))
SPIWP: U10.31 (SPIWP), U11.3 (WP#(IO2))
SYS_5V: C1.1, C19.1, C22.1, C25.1, C28.1, C30.1, C65.1, C67.2, C69.1, L3.1, U2.4 (EN), U2.6 (IN), U4.4 (EN), U4.6 (IN), U5.4 (EN), U5.6 (IN), U6.4 (EN), U6.6 (IN), U7.4 (EN), U7.6 (IN), U9.6 (OUT), U12.5 (VBUS), U15.1 (VIN), U16.4 (IN), U16.5 (IN), U16.6 (IN)
TP_2V8: C2.2, C3.2, FPC2.1, U5.1 (OUT), U5.2 (SNS)
TP_INT_L: FPC2.5, U8.5, U14.3 (A)
TP_INT_L_F: U10.7 (GPIO2), U14.4 (B)
TP_RST_L: FPC2.3, Q4.3 (D), R100.1, U8.2
TP_RST_L_F: R27.2, U10.6 (GPIO1)
TP_SCL_1V8: FPC2.2, R98.2, U8.1, U62.3 (SCL1)
TP_SDA_1V8: FPC2.4, R97.1, U8.4, U62.4 (SDA1)
USB_DN: U12.1 (I/O1), USB1.A7 (DN1), USB1.B7 (DN2)
USB_DP: U12.3 (I/O2), USB1.A6 (DP1), USB1.B6 (DP2)
VBUS: C68.2, R8.2, R24.2, U9.5 (IN), USB1.A4B9 (VBUS), USB1.B4A9 (VBUS)
VDD: C10.1, R24.1, U3.1 (VDD), U3.9 (CFG1)
VDD_SPI: C7.2, C61.2, U10.29 (VDD_SPI), U11.8 (VCC)

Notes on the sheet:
Reset + Boot Buttons
Misc
I2C Pullups
Level Shifter
SPI
USB-C Diode
HDMI
TVS
Touch Clamshell
ESP32
Backlight LED Driver
Decoupling
VBUS Protection
USB-C
PD Controller
HDMI -> MIPI BGA
LDOs
Level Shifters
Display Clamshell

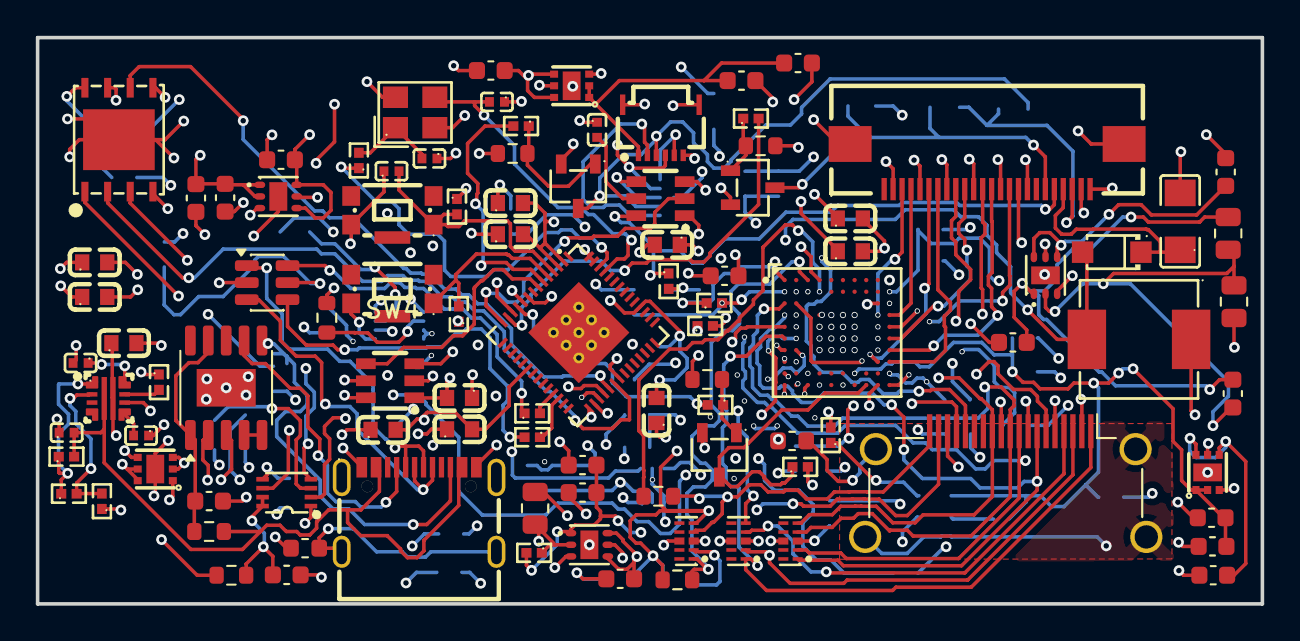
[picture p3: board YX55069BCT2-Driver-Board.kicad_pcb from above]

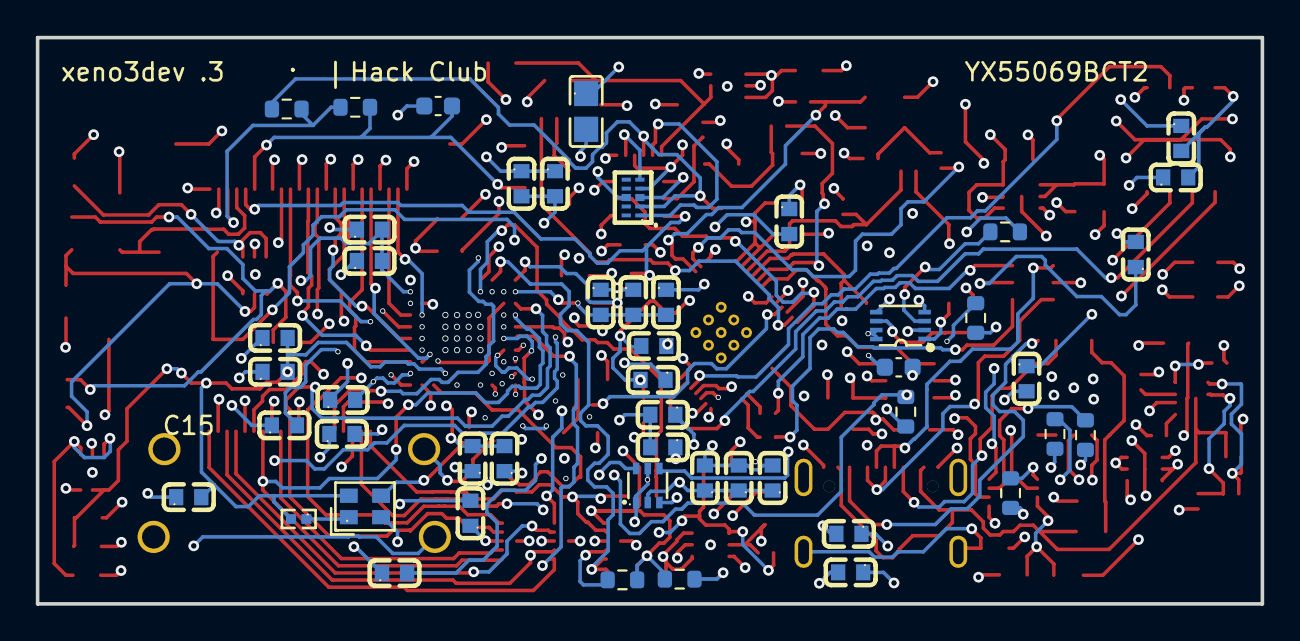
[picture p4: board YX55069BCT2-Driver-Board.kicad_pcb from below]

Board: 8 copper layers, 68.4 x 31.6 mm, 148 parts (49 on the bottom side), 95 nets.

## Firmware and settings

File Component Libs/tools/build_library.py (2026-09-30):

"""One-time import builder. Sources are read-only; outputs stay in this repo.

python build_library.py --slate <slate113_libs> --kicad <share/kicad>
Normal use of the resulting library does NOT require these source installations.
"""
import argparse
import copy
import hashlib
import json
import shutil
from pathlib import Path
from sexpr import Quoted as Q, parse, dump, child, children, walk

ap = argparse.ArgumentParser()
ap.add_argument('--slate', type=Path, required=True)
ap.add_argument('--kicad', type=Path, required=True)
args = ap.parse_args()
base = Path(__file__).resolve().parents[1]
repo = base.parent
nickname = 'YX55069BCT2'
outfp = base / (nickname + '.pretty')
# This directory is generated solely by this script. Clean it to prevent a
# renamed/legacy EasyEDA footprint from surviving a subsequent rebuild.
if outfp.exists():
    shutil.rmtree(outfp)
outfp.mkdir()
symbols, manifest, cache = [], [], {}

def library(path):
    if path not in cache:
        cache[path] = {x[1]: x for x in children(parse(path.read_text(encoding='utf-8')), 'symbol')}
    return cache[path]

def resolved(path, name):
    node = copy.deepcopy(library(path)[name])
    extends = child(node, 'extends')
    if extends:
        parent = resolved(path, extends[1])
        old = parent[1]
        parent[1] = Q(name)
        for sub in children(parent, 'symbol'):
            sub[1] = Q(str(sub[1]).replace(old + '_', name + '_', 1))
        for prop in children(node, 'property'):
            parent[:] = [x for x in parent if not (isinstance(x, list) and x[:2] == prop[:2])]
            parent.append(prop)
        node = parent
    return node

def prop(node, key, value):
    target = next((x for x in children(node, 'property') if x[1] == key), None)
    if target:
        target[2] = Q(value)
    else:
        node.insert(2, ['property', Q(key), Q(value), ['at','0','0','0'], ['effects',['font',['size','1.27','1.27']],['hide','yes']]])

def fp_copy(path):
    node = parse(path.read_text(encoding='utf-8'))
    # No dangling machine-specific/stock-library 3D links. 2D footprint is complete.
    node[:] = [x for x in node if not (isinstance(x,list) and x and x[0] == 'model')]
    # Some Slate EasyEDA footprints carry a library alias in the footprint
    # name itself. A .pretty library must expose an unqualified basename.
    name = str(node[1]).rsplit(':', 1)[-1]
    node[1] = Q(name)
    (outfp / (name + '.kicad_mod')).write_text(dump(node) + '\n', encoding='utf-8')
    return nickname + ':' + name

def add(path, name, new=None, footprint=None, value=None, fields=None):
    node = resolved(path, name)
    new = new or name
    node[1] = Q(new)
    for sub in children(node,'symbol'):
        sub[1] = Q(str(sub[1]).replace(name + '_', new + '_', 1))
    if new != name or value:
        prop(node,'Value',value or new)
    oldfp = next((x[2] for x in children(node,'property') if x[1]=='Footprint'), '')
    if footprint:
        fppath = args.kicad / 'footprints' / (footprint.split(':')[0] + '.pretty') / (footprint.split(':')[1]+'.kicad_mod')
    elif oldfp:
        # Slate's EasyEDA imports carry a legacy three-section alias such as
        # slate113:easyeda2kicad:FPC-....  The final section is the real mod.
        lib = oldfp.split(':', 1)[0]
        fn = oldfp.rsplit(':', 1)[-1]
        fppath = (args.slate / 'slate113.pretty' if lib == 'slate113' else args.kicad / 'footprints' / (lib+'.pretty')) / (fn+'.kicad_mod')
        if lib.endswith('_import'):
            # Locally cached EasyEDA/LCSC imports are kept beside this builder
            # and copied into the portable .pretty output during a rebuild.
            fppath = base / 'sources' / (lib + '.pretty') / (fn+'.kicad_mod')
    else:
        fppath = None
    if fppath:
        prop(node,'Footprint',fp_copy(fppath))
    for k,v in (fields or {}).items():
        prop(node,k,v)
    # Historical EasyEDA IDs do not belong in current library syntax.
    for p in children(node,'property'):
        p[:] = [x for x in p if not (isinstance(x,list) and x and x[0]=='id')]
    symbols.append(node)
    manifest.append({'symbol':new,'source_library':path.name,'source_symbol':name,
                     'source_sha256':hashlib.sha256(path.read_bytes()).hexdigest(),
                     'footprint':next((x[2] for x in children(node,'property') if x[1]=='Footprint'),'')})
    return node

slate = args.slate / 'slate113.kicad_sym'
exact = {
    'TYPE-C16PIN': {'MPN':'TYPE-C16PIN','Manufacturer':'Shou Han','LCSC':'C393939',
                    'Datasheet':'https://www.lcsc.com/product-detail/C393939.html'},
    'FPC0.5-24P': {'MPN':'F-FPC0M24P-C310','Manufacturer':'CKMTW','LCSC':'C132514',
                   'Datasheet':'https://www.lcsc.com/product-detail/C132514.html'},
    'FPC-0.5FX-6PWBH10': {'MPN':'FPC-0.5FX-6PWBH10','Manufacturer':'Xunpu','LCSC':'C5343255',
                          'Datasheet':'https://www.lcsc.com/product-detail/C5343255.html'},
    'PCA9306DCUR': {'MPN':'PCA9306DCUR','Manufacturer':'TI','LCSC':'C33196',
                    'Datasheet':'https://www.ti.com/product/PCA9306'},
    'AP2112K-3.3TRG1': {'MPN':'AP2112K-3.3TRG1','Manufacturer':'Diodes','LCSC':'C51118',
                        'Datasheet':'https://www.diodes.com/part/view/AP2112'},
    'AP2112K-1.8TRG1': {'MPN':'AP2112K-1.8TRG1','Manufacturer':'Diodes','LCSC':'C176944',
                        'Datasheet':'https://www.diodes.com/part/view/AP2112'},
    'AP2120N-2.8TRG1': {'MPN':'AP2120N-2.8TRG1','Manufacturer':'Diodes','LCSC':'C6500826',
                        'Datasheet':'https://www.diodes.com/datasheet/download/AP2120.pdf'},
    'LP8556SQ-E09_NOPB': {'MPN':'LP8556SQ-E09/NOPB','Manufacturer':'TI','LCSC':'C2679180',
                          'Datasheet':'https://www.ti.com/lit/ds/symlink/lp8556.pdf'},
}
for name, fields in exact.items():
    add(slate,name,fields={'Source':'Slate113 project library; imported without editing source', **fields})
add(args.kicad/'symbols/Regulator_Linear.kicad_sym','AP2112K-1.2',new='AP2112K-1.2TRG1',
    fields={'MPN':'AP2112K-1.2TRG1','Manufacturer':'Diodes','LCSC':'C460310',
            'Datasheet':'https://www.diodes.com/part/view/AP2112',
            'Role':'Dedicated 1.2 V TC358870 MIPI D-PHY rail; do not merge with 1.1 V rails.'})
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

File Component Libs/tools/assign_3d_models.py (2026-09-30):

"""Attach verified local/stock STEP models to the portable library and PCB.

Run after build_library.py when regenerating the project library.
"""
from pathlib import Path
import shutil
import subprocess

from sexpr import Quoted, parse, dump, children

base = Path(__file__).resolve().parents[1]
project = base.parent / "Kicad Project"
library = base / "YX55069BCT2.pretty"
shapes = base / "YX55069BCT2.3dshapes"
sources = base / "sources"
slate = Path(r"C:\Users\Aylon\GitHub\slate113-mk1\Kicad Project\slate113_libs\slate113.3dshapes")
pcb = project / "YX55069BCT2-Driver-Board.kicad_pcb"

# A stock KiCad model is used only when its footprint/body dimensions match.
stock = {
    "C0402": "Capacitor_SMD.3dshapes/C_0402_1005Metric.step",
    "C0603": "Capacitor_SMD.3dshapes/C_0603_1608Metric.step",
    "C0805": "Capacitor_SMD.3dshapes/C_0805_2012Metric.step",
    "CL05A105KA5NQNC": "Capacitor_SMD.3dshapes/C_0402_1005Metric.step",
    "C_0603_1608Metric": "Capacitor_SMD.3dshapes/C_0603_1608Metric.step",
    "R0402": "Resistor_SMD.3dshapes/R_0402_1005Metric.step",
    "R_0603_1608Metric": "Resistor_SMD.3dshapes/R_0603_1608Metric.step",
    "L_0603_1608Metric": "Inductor_SMD.3dshapes/L_0603_1608Metric.step",
    "HDMI_A_Amphenol_10029449-x01xLF_Horizontal": "Connector_Video.3dshapes/HDMI_A_Amphenol_10029449-x01xLF_Horizontal.step",
}
vendor = {
    "P-VFBGA-80_L7.0-W7.0-R10-C10-P0.65-TL": "tc358870_import.3dshapes/P-VFBGA-80_L7.0-W7.0-H0.9-R10-C10-P0.65-TL.step",
    "C1206": "C100122_import.3dshapes/C1206_L3.2-W1.6-H1.3.step",
    "CRYSTAL-SMD_4P-L3.2-W2.5-BL": "C1986736_import.3dshapes/CRYSTAL-SMD_4P-L3.2-W2.5-BL.step",
    "OSC-SMD_4P-L2.0-W1.6-BL": "OT7EL89CJI-111YLC-48M_import.3dshapes/OSC-SMD_4P-L2.0-W1.6-H0.8.step",
    "QFN-56_L7.0-W7.0-P0.40-TL-EP4.0": "C2913194_import.3dshapes/QFN-56_L7.0-W7.0-P0.40-TL-EP4.0.step",
    "SOD-123FL_L2.7-W1.8-LS3.8-RD": "C405304_import.3dshapes/SOD-123FL_L2.8-W1.8-H1.1-LS3.6.step",
    "SOT-23-3_L2.9-W1.6-P1.90-LS2.8-BR": "C112239_import.3dshapes/SOT-23-3L_L2.9-W1.6-H1.1-LS2.8-P0.95.step",
    "SOT-23-6_L2.9-W1.6-P0.95-LS2.8-BR": "C132604_import.3dshapes/SOT-23-6_L2.9-W1.6-H1.5-LS2.8-P0.95.step",
    "USON-10_L2.5-W1.0-P0.50-BL": "C138714_import.3dshapes/USON-10_L2.5-W1.0-H0.6-P0.50.step",
    "VQFN-10_L2.0-W2.0-P0.45-TL": "C2864845_import.3dshapes/VQFN-10_L2.0-W2.0-P0.45-TL.step",
    "WSON-6_L2.0-W2.0-P0.65-BL-EP": "TLV767_import.3dshapes/WSON-6_L2.0-W2.0-H0.8-P0.65.step",
    "WSON-6_L2.0-W2.0-P0.65-TL-EP": "TLV767_import.3dshapes/WSON-6_L2.0-W2.0-H0.8-P0.65.step",
    "WSON-8_L6.0-W5.0-P1.27-TL-EP": "C2982923_import.3dshapes/WSON-8_L6.0-W5.0-P1.27-TL-EP.step",
}

def model_for(name):
    if name in stock:
        path = Path(r"C:\Program Files\KiCad\10.0\share\kicad\3dmodels") / stock[name]
        assert path.is_file(), path
        return "${KICAD10_3DMODEL_DIR}/" + stock[name]
    if name == "USB-C-SMD_TYPE-C16PIN":
        source = slate / "USB-C-SMD_TYPE-C16PIN.step"
    elif name in vendor:
        source = sources / vendor[name]
    else:
        return None
    assert source.is_file(), source
    shapes.mkdir(exist_ok=True)
    target = shapes / source.name
    if not target.exists():
        shutil.copy2(source, target)
    return "${KIPRJMOD}/../Component Libs/YX55069BCT2.3dshapes/" + target.name

def rotation_for(name):
    if name not in vendor:
        return "0"
    source_fp = sources / (vendor[name].split("/", 1)[0].replace(".3dshapes", ".pretty")) / (name + ".kicad_mod")
    if not source_fp.is_file():
        return "0"
    source_node = parse(source_fp.read_text(encoding="utf-8"))
    models = children(source_node, "model")
    if not models:
        return "0"
    rotation = children(models[0], "rotate")
    return str(rotation[0][1][3]) if rotation else "0"

def add_model(node, path, name):
    if children(node, "model"):
        return False
    node.append(["model", Quoted(path),
                 ["offset", ["xyz", "0", "0", "0"]],
                 ["scale", ["xyz", "1", "1", "1"]],
                 ["rotate", ["xyz", "0", "0", rotation_for(name)]]])
    return True

assigned = set()
for path in library.glob("*.kicad_mod"):
    model = model_for(path.stem)
    if model:
        node = parse(path.read_text(encoding="utf-8"))
        node[:] = [x for x in node if not (isinstance(x, list) and x and x[0] == "model"
                                      and str(x[1]) == model)]
        if add_model(node, model, path.stem):
            path.write_text(dump(node) + "\n", encoding="utf-8")
        assigned.add(path.stem)

def footprint_ranges(text):
    """Yield exact top-level footprint spans without reformatting the board."""
    i = 0
    while True:
        start = text.find('\n\t(footprint ', i)
        if start < 0:
            return
        start += 2
        depth, quoted, escaped = 0, False, False
        for end in range(start, len(text)):
            c = text[end]
            if quoted:
                if escaped:
                    escaped = False
                elif c == '\\':
                    escaped = True
                elif c == '"':
                    quoted = False
            elif c == '"':
                quoted = True
            elif c == '(':
                depth += 1
            elif c == ')':
                depth -= 1
                if depth == 0:
                    yield start, end + 1
                    i = end + 1
                    break
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

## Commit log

2026-09-28 wired up esp32 + almost done with HDMI -> MIPI Converter
    [02485e56ba8d4732a26526d2983fc729.obj, 02485e56ba8d4732a26526d2983fc729.step, 026a4a15ab5c4a92ac0e421d6d013717.obj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]
2026-09-28 wired up remaining components
    [YX55069BCT2-Driver-Board.kicad_sch, df0eca6a71854020b6cf420855c3797f.obj, df0eca6a71854020b6cf420855c3797f.step]
2026-09-30 made final schematic changes
    [229b69761e2c45dba6a83d8866dec72d.obj, 229b69761e2c45dba6a83d8866dec72d.step, 262834a5342148ebb2da8f3848ec58ce.obj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]
2026-09-30 started PCB work + wire up most of the HDMI -> MIPI converter BGA & ESP32
    [YX55069BCT2-Driver-Board.kicad_pcb, YX55069BCT2-Driver-Board.kicad_sch]
2026-09-30 wired up LDOs + USB-C
    [YX55069BCT2-Driver-Board.kicad_pcb]
2026-09-30 wired rest of components, and majority of remaining caps and resistors
    [YX55069BCT2-Driver-Board.kicad_pcb, YX55069BCT2-Driver-Board.kicad_sch]
2026-10-01 wired up rest of components
    [YX55069BCT2-Driver-Board.kicad_pcb]
2026-10-01 fixed most of DRC errors
    [YX55069BCT2-Driver-Board.kicad_pcb, YX55069BCT2-Driver-Board.kicad_sch]
2026-10-01 fixed remaining DRC issues
    [YX55069BCT2-Driver-Board.kicad_pcb]
2026-10-02 add README + production files
    [02485e56ba8d4732a26526d2983fc729.obj, 02485e56ba8d4732a26526d2983fc729.step, 026a4a15ab5c4a92ac0e421d6d013717.obj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]

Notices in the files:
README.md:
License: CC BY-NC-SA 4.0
